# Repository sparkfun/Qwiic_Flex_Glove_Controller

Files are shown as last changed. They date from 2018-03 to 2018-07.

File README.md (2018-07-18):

SparkFun Qwiic Flex Glove Controller
========================================

SparkFun Qwiic Flex Glove Controller

[*SparkFun Qwiic Flex Glove Controller (Sen-14666)*](https://www.sparkfun.com/products/14666)

This board is a breakout for multiple flex sensors that keeps the solder points isolated to avoid breakage in wearable projects.

Repository Contents
-------------------

* **/Hardware** - Eagle design files (.brd, .sch)
* **/Libraries** - Libraries for use with the <PRODUCT NAME>
* **/Production** - Production panel files (.brd)

Documentation
--------------
* **[ADS1015 Library](https://github.com/sparkfun/SparkFun_ADS1015_Arduino_Library)** - C++ library for the ADS1015.
* **[Hookup Guide](https://learn.sparkfun.com/tutorials/qwiic-flex-glove-controller-hookup-guide)** - Basic hookup guide for the Qwiic Flex Glove Controller.

Product Versions
----------------
* [SEN-14666](https://www.sparkfun.com/products/14666)- The SparkFun Qwiic Flex Glove Controller allows you to incorporate flex sensors into a glove to control lighting, sound, and other effects making it perfect for wearable and e-textile applications. All communication is enacted exclusively via I2C, utilizing our handy Qwiic system. 

License Information
-------------------

This product is _**open source**_! 

Please review the LICENSE.md file for license information. 

If you have any questions or concerns on licensing, please contact techsupport@sparkfun.com.

Distributed as-is; no warranty is given.

- Your friends at SparkFun.

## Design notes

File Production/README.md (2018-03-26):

SparkFun <PRODUCT NAME> Production Files
=========================================

These are the production files SparkFun uses for printing PCBs.

License Information
-------------------
This product is open source! 

The hardware is released under [Creative Commons ShareAlike 4.0 International](https://creativecommons.org/licenses/by-sa/4.0/).

Please use, reuse, and modify these files as you see fit. Please maintain attribution to SparkFun Electronics and release anything derivative under the same license.

Distributed as-is; no warranty is given.

- Your friends at SparkFun.

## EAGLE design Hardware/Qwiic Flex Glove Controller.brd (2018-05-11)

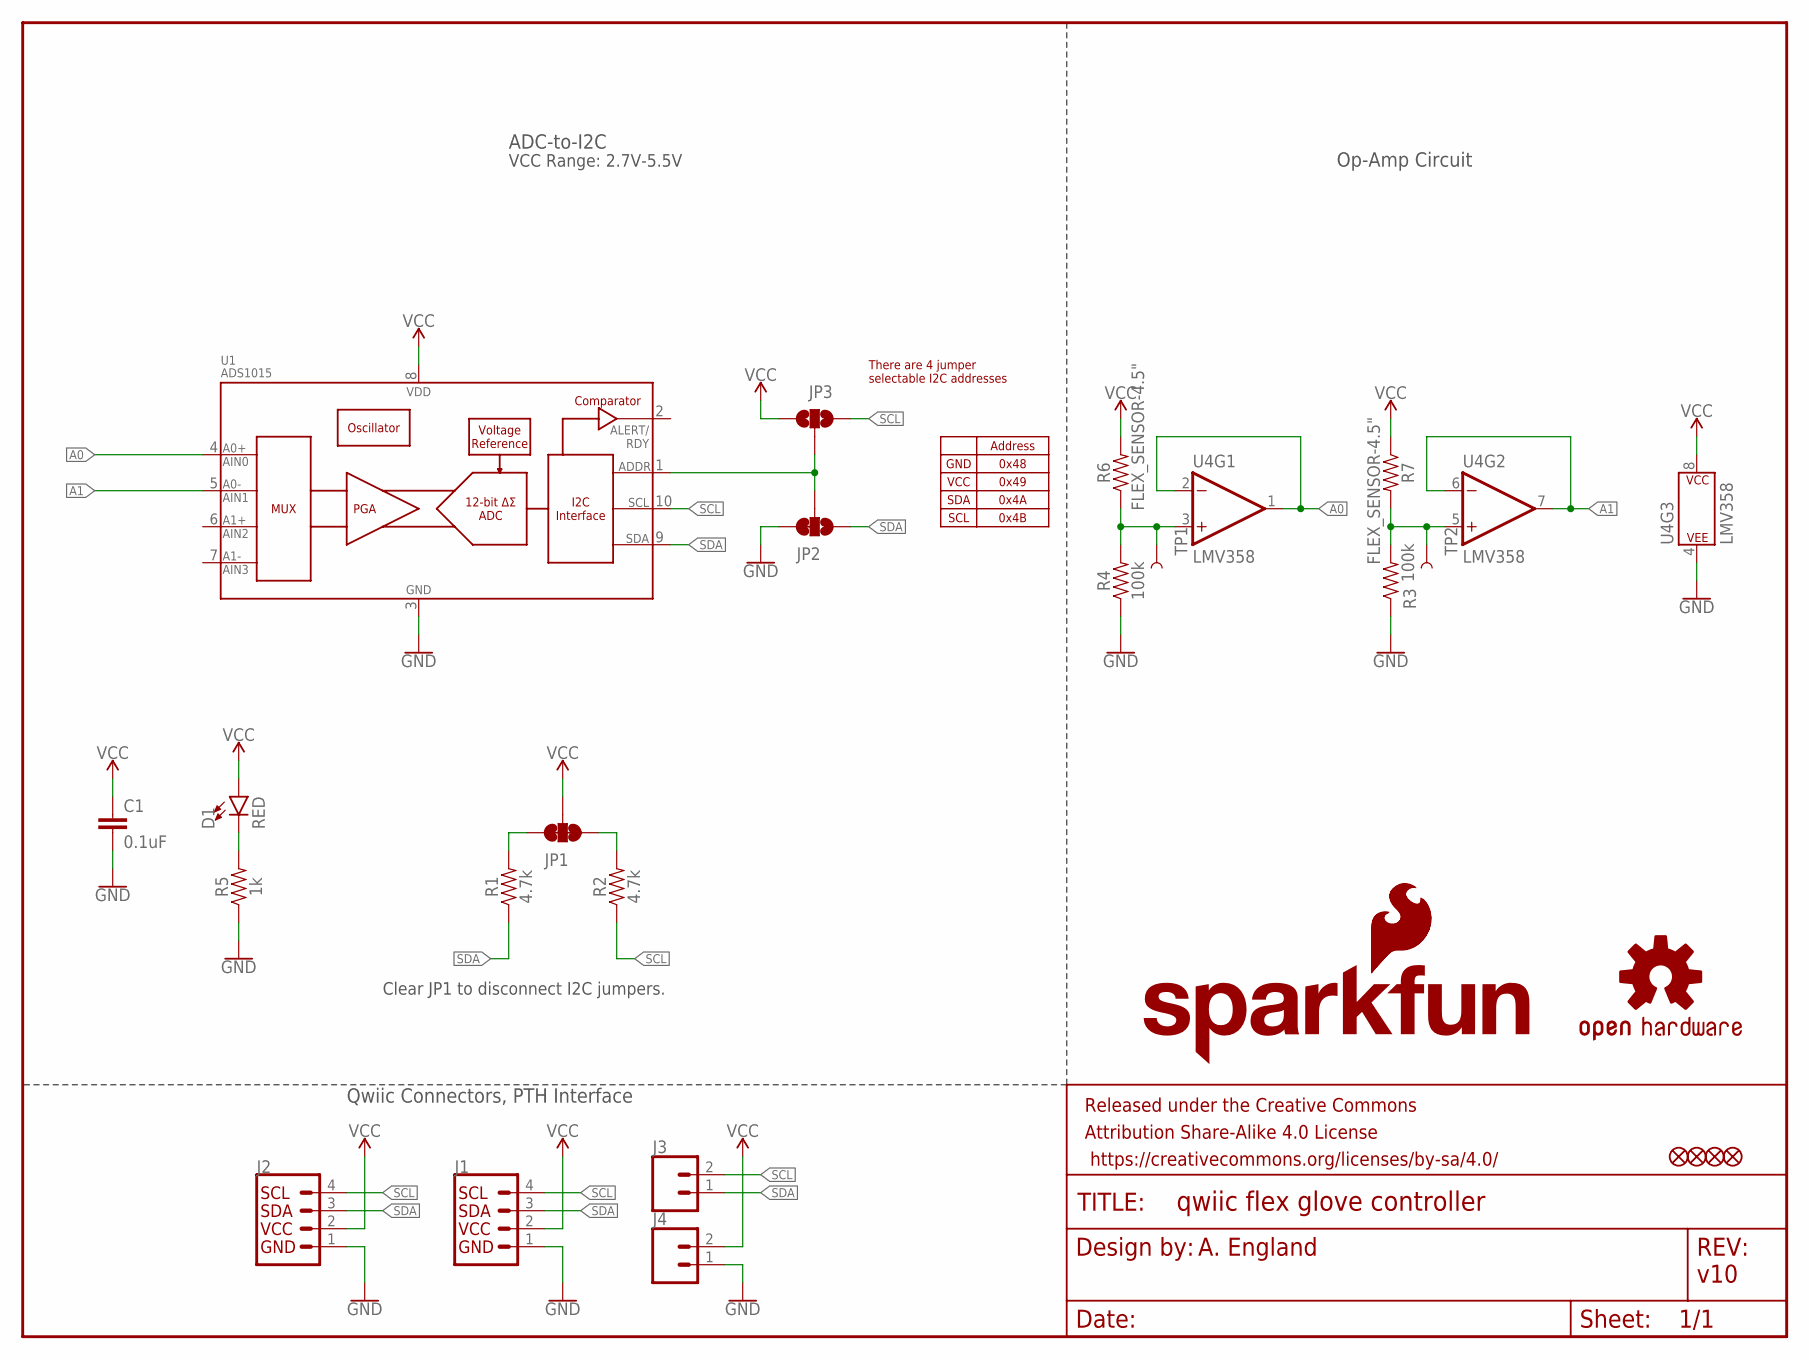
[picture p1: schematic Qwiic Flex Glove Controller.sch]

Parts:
C1: 0.1uF; 0603
D1: RED; LED-0603
FD1, FD2, FD3, FD4: FIDUCIALUFIDUCIAL; FIDUCIAL-MICRO
FRAME1: FRAME-LETTER; CREATIVE_COMMONS
J1, J2: QWIIC_CONNECTORJS-1MM; 1X04_1MM_RA
J3, J4: CONN_02; 1X02
JP1: JUMPER-SMT_3_2-NC_TRACE_NO-SILK; SMT-JUMPER_3_2-NC_TRACE_NO-SILK
JP2: JUMPER-SMT_3_1-NC_TRACE_NO-SILK; SMT-JUMPER_3_1-NC_TRACE_NO-SILK
JP3: JUMPER-SMT_3_NO_NO_SILK; SMT-JUMPER_3_0-NO_TRACE_NO-SILK
LOGO1: SFE_LOGO_NAME_FLAME.1_INCH; SFE_LOGO_NAME_FLAME_.1
LOGO2: OSHW-LOGOS; OSHW-LOGO-S
LOGO3: SFE_LOGO_FLAME.1_INCH; SFE_LOGO_FLAME_.1
R1, R2: 4.7k; 0603
R3, R4: 100k; 0603
R5: 1k; 0603
R6, R7: FLEX_SENSOR-4.5"; FLEX_SENSOR
TP1, TP2: TEST-POINT3; PAD.03X.03
U1: ADS1015; MSOP10
U4: LMV358; SO08

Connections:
A0: U1.4 (AIN0), U4.1 (OUT), U4.2 (-IN)
A1: U1.5 (AIN1), U4.6 (-IN), U4.7 (OUT)
GND: C1.2, J1.1, J2.1, J4.1, JP2.3, R3.1, R4.1, R5.1, U1.3 (VSS), U4.4 (P$V-)
unnamed: JP2.2, JP3.2, U1.1 (ADDR)
unnamed: D1.C, R5.2
unnamed: R3.2, R7.P$2 (2), TP2.P$1, U4.5 (+IN)
unnamed: R4.2, R6.P$1 (1), TP1.P$1, U4.3 (+IN)
unnamed: JP1.1, R2.2
unnamed: JP1.3, R1.2
SCL: J1.4, J2.4, J3.2, JP3.3, R2.1, U1.10 (SCL)
SDA: J1.3, J2.3, J3.1, JP2.1, R1.1, U1.9 (SDA)
VCC: C1.1, D1.A, J1.2, J2.2, J4.2, JP1.2, JP3.1, R6.P$2 (2), R7.P$1 (1), U1.8 (VDD), U4.8 (P$V+)

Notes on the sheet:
v10
Qwiic Connectors, PTH Interface
ADC-to-I2C
Op-Amp Circuit
A. England
There are 4 jumper selectable I2C addresses
Address
0x48
0x49
0x4A
0x4B
GND
VCC
SDA
SCL
VCC Range: 2.7V-5.5V
Clear JP1 to disconnect I2C jumpers.

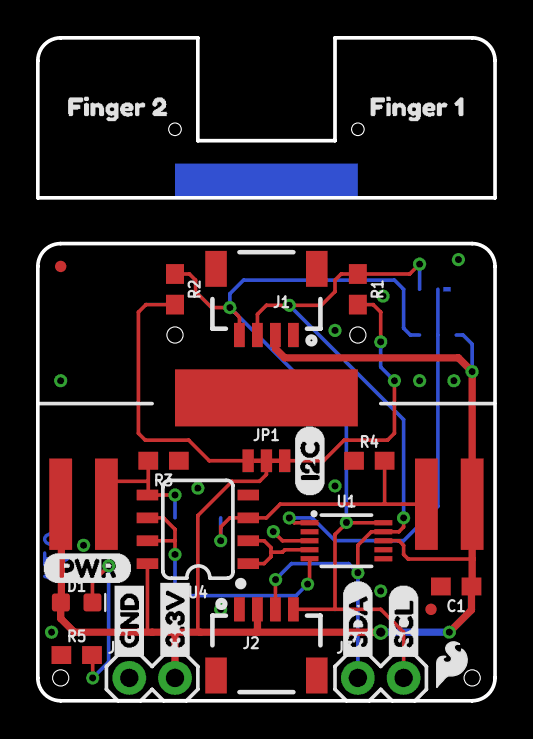
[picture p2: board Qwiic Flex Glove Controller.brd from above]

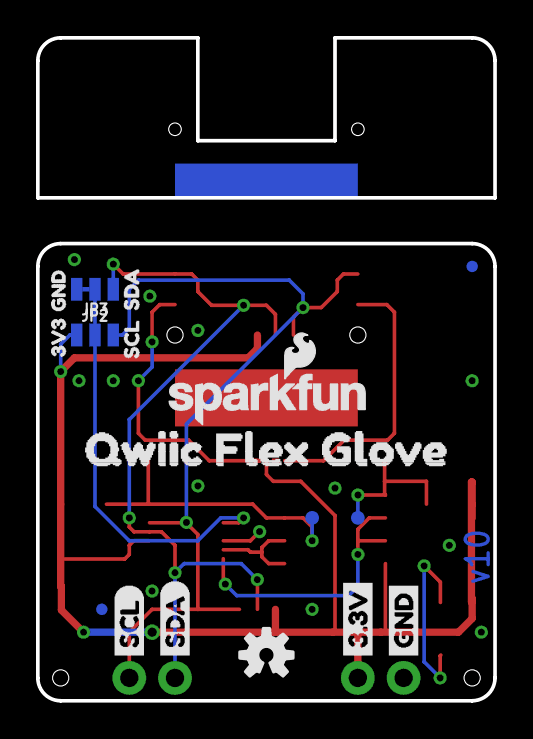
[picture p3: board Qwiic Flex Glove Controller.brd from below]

Board: 2 copper layers, 25.4 x 36.8 mm, 45 parts (17 on the bottom side), 12 nets.

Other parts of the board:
U$1, U$2: GND
U$3: 3V3-TEXT
U$4: GND-TEXT-03
U$5, U$6: 3.3V
U$7, U$8: SDA
U$9, U$10: SCL
U$11: (PWR)
U$12: SDA0
U$13: SCL2
U$14: QWIIC_FLEX_GLOVE0
U$15: I2C-()
U$16: FINGER_10
U$17: FINGER_21

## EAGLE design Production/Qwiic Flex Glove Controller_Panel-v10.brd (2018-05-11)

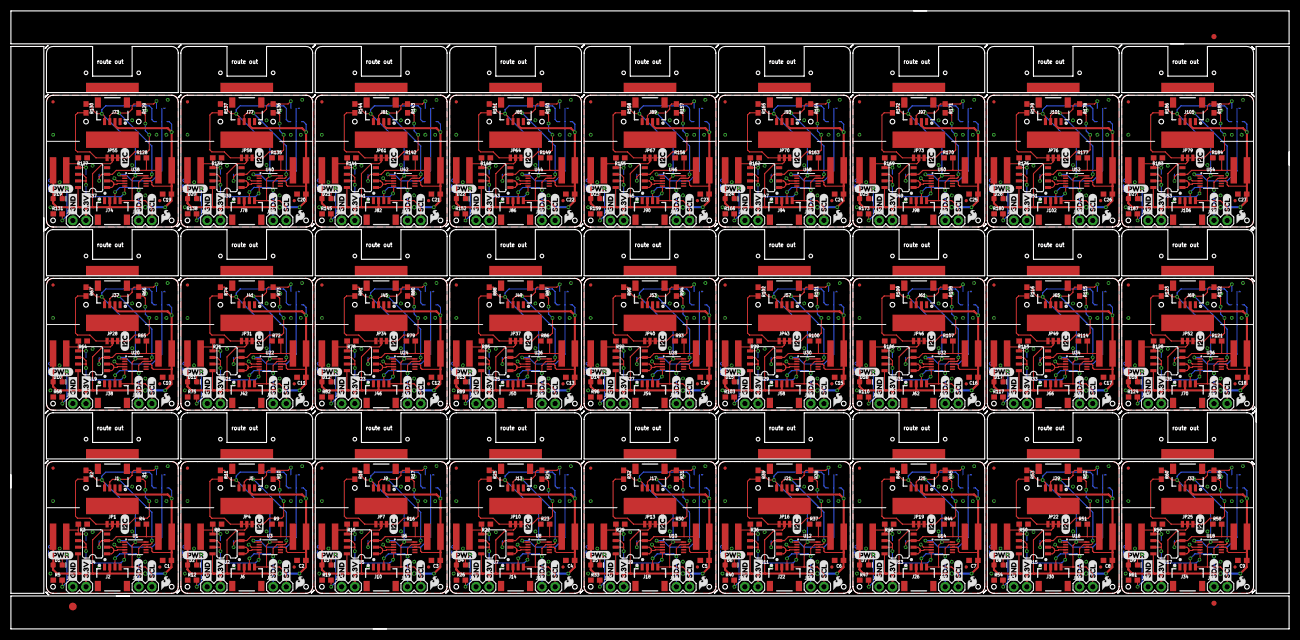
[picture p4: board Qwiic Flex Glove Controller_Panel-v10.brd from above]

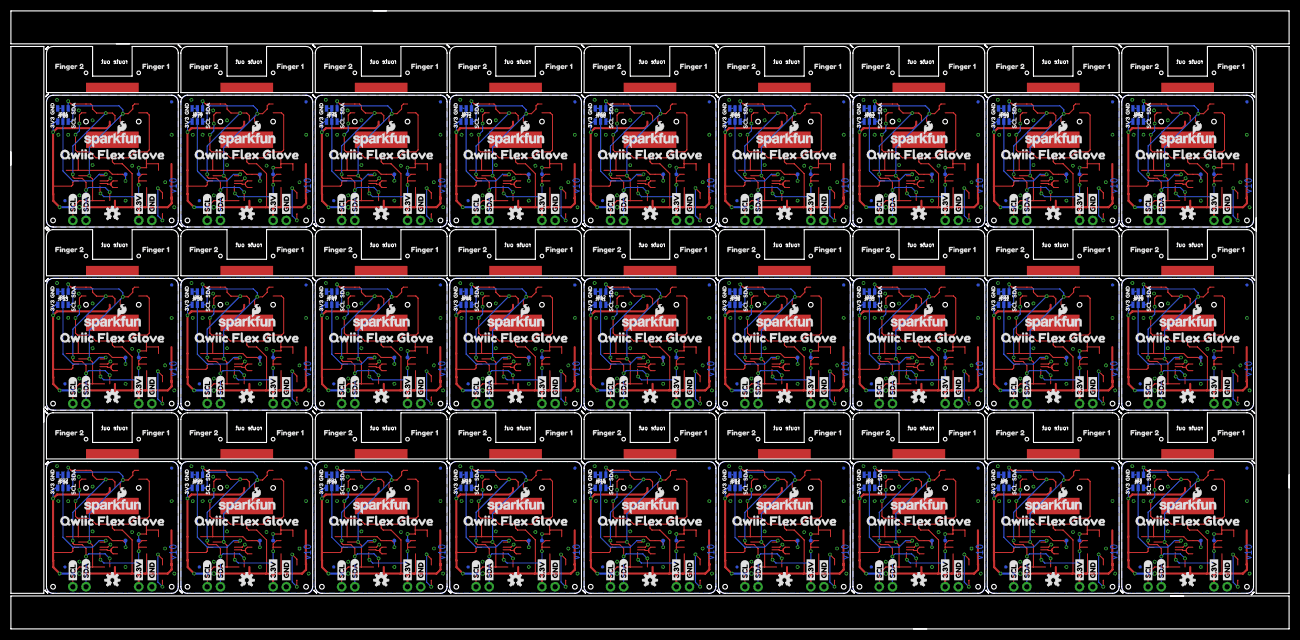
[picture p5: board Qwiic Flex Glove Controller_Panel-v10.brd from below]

Board: 2 copper layers, 246.4 x 119.1 mm, 1191 parts (513 on the bottom side), 324 nets.

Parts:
C1, C2, C3, C4, C5, C6, C7, C8, C9, C10, C11, C12, C13, C14, C15, C16, C17, C18, C19, C20, C21, C22, C23, C24, C25, C26, C27: 0.1uF; 0603
D1, D2, D3, D4, D5, D6, D7, D8, D9, D10, D11, D12, D13, D14, D15, D16, D17, D18, D19, D20, D21, D22, D23, D24, D25, D26, D27: RED; LED-0603
E$1: FIDUCIAL-1.5X3
E$5, E$6: FIDUCIAL-1X2
FD1, FD2, FD3, FD4, FD5, FD6, FD7, FD8, FD9, FD10, FD11, FD12, FD13, FD14, FD15, FD16, FD17, FD18, FD19, FD20, FD21, FD22, FD23, FD24, FD25, FD26, FD27, FD28, FD29, FD30, FD31, FD32, FD33, FD34, FD35, FD36, FD37, FD38, FD39, FD40, FD41, FD42, FD43, FD44, FD45, FD46, FD47, FD48, FD49, FD50, FD51, FD52, FD53, FD54, FD55, FD56, FD57, FD58, FD59, FD60, FD61, FD62, FD63, FD64, FD65, FD66, FD67, FD68, FD69, FD70, FD71, FD72, FD73, FD74, FD75, FD76, FD77, FD78, FD79, FD80, FD81, FD82, FD83, FD84, FD85, FD86, FD87, FD88, FD89, FD90, FD91, FD92, FD93, FD94, FD95, FD96, FD97, FD98, FD99, FD100, FD101, FD102, FD103, FD104, FD105, FD106, FD107, FD108: FIDUCIALUFIDUCIAL; FIDUCIAL-MICRO
J1, J2, J5, J6, J9, J10, J13, J14, J17, J18, J21, J22, J25, J26, J29, J30, J33, J34, J37, J38, J41, J42, J45, J46, J49, J50, J53, J54, J57, J58, J61, J62, J65, J66, J69, J70, J73, J74, J77, J78, J81, J82, J85, J86, J89, J90, J93, J94, J97, J98, J101, J102, J105, J106: 1X04_1MM_RA
J3, J4, J7, J8, J11, J12, J15, J16, J19, J20, J23, J24, J27, J28, J31, J32, J35, J36, J39, J40, J43, J44, J47, J48, J51, J52, J55, J56, J59, J60, J63, J64, J67, J68, J71, J72, J75, J76, J79, J80, J83, J84, J87, J88, J91, J92, J95, J96, J99, J100, J103, J104, J107, J108: 1X02
JP1, JP4, JP7, JP10, JP13, JP16, JP19, JP22, JP25, JP28, JP31, JP34, JP37, JP40, JP43, JP46, JP49, JP52, JP55, JP58, JP61, JP64, JP67, JP70, JP73, JP76, JP79: JUMPER-SMT_3_2-NC_TRACE_NO-SILK; SMT-JUMPER_3_2-NC_TRACE_NO-SILK
JP2, JP5, JP8, JP11, JP14, JP17, JP20, JP23, JP26, JP29, JP32, JP35, JP38, JP41, JP44, JP47, JP50, JP53, JP56, JP59, JP62, JP65, JP68, JP71, JP74, JP77, JP80: JUMPER-SMT_3_1-NC_TRACE_NO-SILK; SMT-JUMPER_3_1-NC_TRACE_NO-SILK
JP3, JP6, JP9, JP12, JP15, JP18, JP21, JP24, JP27, JP30, JP33, JP36, JP39, JP42, JP45, JP48, JP51, JP54, JP57, JP60, JP63, JP66, JP69, JP72, JP75, JP78, JP81: JUMPER-SMT_3_NO_NO_SILK; SMT-JUMPER_3_0-NO_TRACE_NO-SILK
LOGO1, LOGO4, LOGO7, LOGO10, LOGO13, LOGO16, LOGO19, LOGO22, LOGO25, LOGO28, LOGO31, LOGO34, LOGO37, LOGO40, LOGO43, LOGO46, LOGO49, LOGO52, LOGO55, LOGO58, LOGO61, LOGO64, LOGO67, LOGO70, LOGO73, LOGO76, LOGO79: SFE_LOGO_NAME_FLAME.1_INCH; SFE_LOGO_NAME_FLAME_.1
LOGO2, LOGO5, LOGO8, LOGO11, LOGO14, LOGO17, LOGO20, LOGO23, LOGO26, LOGO29, LOGO32, LOGO35, LOGO38, LOGO41, LOGO44, LOGO47, LOGO50, LOGO53, LOGO56, LOGO59, LOGO62, LOGO65, LOGO68, LOGO71, LOGO74, LOGO77, LOGO80: OSHW-LOGOS; OSHW-LOGO-S
LOGO3, LOGO6, LOGO9, LOGO12, LOGO15, LOGO18, LOGO21, LOGO24, LOGO27, LOGO30, LOGO33, LOGO36, LOGO39, LOGO42, LOGO45, LOGO48, LOGO51, LOGO54, LOGO57, LOGO60, LOGO63, LOGO66, LOGO69, LOGO72, LOGO75, LOGO78, LOGO81: SFE_LOGO_FLAME.1_INCH; SFE_LOGO_FLAME_.1
R1, R2, R10, R11, R17, R18, R24, R25, R31, R32, R38, R39, R45, R46, R52, R53, R59, R60, R66, R67, R73, R74, R80, R81, R87, R88, R94, R95, R101, R102, R108, R109, R115, R116, R122, R123, R129, R130, R136, R137, R143, R144, R150, R151, R157, R158, R164, R165, R171, R172, R178, R179, R185, R186: 4.7k; 0603
R3, R4, R8, R9, R15, R16, R22, R23, R29, R30, R36, R37, R43, R44, R50, R51, R57, R58, R64, R65, R71, R72, R78, R79, R85, R86, R92, R93, R99, R100, R106, R107, R113, R114, R120, R121, R127, R128, R134, R135, R141, R142, R148, R149, R155, R156, R162, R163, R169, R170, R176, R177, R183, R184: 100k; 0603
R5, R12, R19, R26, R33, R40, R47, R54, R61, R68, R75, R82, R89, R96, R103, R110, R117, R124, R131, R138, R145, R152, R159, R166, R173, R180, R187: 1k; 0603
R6, R7, R13, R14, R20, R21, R27, R28, R34, R35, R41, R42, R48, R49, R55, R56, R62, R63, R69, R70, R76, R77, R83, R84, R90, R91, R97, R98, R104, R105, R111, R112, R118, R119, R125, R126, R132, R133, R139, R140, R146, R147, R153, R154, R160, R161, R167, R168, R174, R175, R181, R182, R188, R189: FLEX_SENSOR-4.5"; FLEX_SENSOR
TP1, TP2, TP3, TP4, TP5, TP6, TP7, TP8, TP9, TP10, TP11, TP12, TP13, TP14, TP15, TP16, TP17, TP18, TP19, TP20, TP21, TP22, TP23, TP24, TP25, TP26, TP27, TP28, TP29, TP30, TP31, TP32, TP33, TP34, TP35, TP36, TP37, TP38, TP39, TP40, TP41, TP42, TP43, TP44, TP45, TP46, TP47, TP48, TP49, TP50, TP51, TP52, TP53, TP54: TEST-POINT3; PAD.03X.03
U1, U3, U6, U8, U10, U12, U14, U16, U18, U20, U22, U24, U26, U28, U30, U32, U34, U36, U38, U40, U42, U44, U46, U48, U50, U52, U54: ADS1015; MSOP10
U2, U4, U5, U7, U9, U11, U13, U15, U17, U19, U21, U23, U25, U27, U29, U31, U33, U35, U37, U39, U41, U43, U45, U47, U49, U51, U53: LMV358; SO08
U$1, U$2, U$18, U$19, U$35, U$36, U$52, U$53, U$69, U$70, U$86, U$87, U$103, U$104, U$120, U$121, U$137, U$138, U$154, U$155, U$171, U$172, U$188, U$189, U$205, U$206, U$222, U$223, U$239, U$240, U$256, U$257, U$273, U$274, U$290, U$291, U$307, U$308, U$324, U$325, U$341, U$342, U$358, U$359, U$375, U$376, U$392, U$393, U$409, U$410, U$426, U$427, U$443, U$444: GND
U$3, U$27, U$44, U$61, U$78, U$95, U$112, U$129, U$146, U$163, U$180, U$197, U$214, U$231, U$248, U$265, U$282, U$299, U$316, U$333, U$350, U$367, U$384, U$401, U$418, U$435, U$452: 3V3-TEXT
U$4, U$28, U$45, U$62, U$79, U$96, U$113, U$130, U$147, U$164, U$181, U$198, U$215, U$232, U$249, U$266, U$283, U$300, U$317, U$334, U$351, U$368, U$385, U$402, U$419, U$436, U$453: GND-TEXT-03
U$5, U$6, U$20, U$21, U$37, U$38, U$54, U$55, U$71, U$72, U$88, U$89, U$105, U$106, U$122, U$123, U$139, U$140, U$156, U$157, U$173, U$174, U$190, U$191, U$207, U$208, U$224, U$225, U$241, U$242, U$258, U$259, U$275, U$276, U$292, U$293, U$309, U$310, U$326, U$327, U$343, U$344, U$360, U$361, U$377, U$378, U$394, U$395, U$411, U$412, U$428, U$429, U$445, U$446: 3.3V
U$7, U$8, U$22, U$23, U$39, U$40, U$56, U$57, U$73, U$74, U$90, U$91, U$107, U$108, U$124, U$125, U$141, U$142, U$158, U$159, U$175, U$176, U$192, U$193, U$209, U$210, U$226, U$227, U$243, U$244, U$260, U$261, U$277, U$278, U$294, U$295, U$311, U$312, U$328, U$329, U$345, U$346, U$362, U$363, U$379, U$380, U$396, U$397, U$413, U$414, U$430, U$431, U$447, U$448: SDA
U$9, U$10, U$24, U$25, U$41, U$42, U$58, U$59, U$75, U$76, U$92, U$93, U$109, U$110, U$126, U$127, U$143, U$144, U$160, U$161, U$177, U$178, U$194, U$195, U$211, U$212, U$228, U$229, U$245, U$246, U$262, U$263, U$279, U$280, U$296, U$297, U$313, U$314, U$330, U$331, U$347, U$348, U$364, U$365, U$381, U$382, U$398, U$399, U$415, U$416, U$432, U$433, U$449, U$450: SCL
U$11, U$26, U$43, U$60, U$77, U$94, U$111, U$128, U$145, U$162, U$179, U$196, U$213, U$230, U$247, U$264, U$281, U$298, U$315, U$332, U$349, U$366, U$383, U$400, U$417, U$434, U$451: (PWR)
U$12, U$29, U$46, U$63, U$80, U$97, U$114, U$131, U$148, U$165, U$182, U$199, U$216, U$233, U$250, U$267, U$284, U$301, U$318, U$335, U$352, U$369, U$386, U$403, U$420, U$437, U$454: SDA0
U$13, U$30, U$47, U$64, U$81, U$98, U$115, U$132, U$149, U$166, U$183, U$200, U$217, U$234, U$251, U$268, U$285, U$302, U$319, U$336, U$353, U$370, U$387, U$404, U$421, U$438, U$455: SCL2
U$14, U$32, U$49, U$66, U$83, U$100, U$117, U$134, U$151, U$168, U$185, U$202, U$219, U$236, U$253, U$270, U$287, U$304, U$321, U$338, U$355, U$372, U$389, U$406, U$423, U$440, U$457: QWIIC_FLEX_GLOVE0
U$15, U$31, U$48, U$65, U$82, U$99, U$116, U$133, U$150, U$167, U$184, U$201, U$218, U$235, U$252, U$269, U$286, U$303, U$320, U$337, U$354, U$371, U$388, U$405, U$422, U$439, U$456: I2C-()
U$16, U$33, U$50, U$67, U$84, U$101, U$118, U$135, U$152, U$169, U$186, U$203, U$220, U$237, U$254, U$271, U$288, U$305, U$322, U$339, U$356, U$373, U$390, U$407, U$424, U$441, U$458: FINGER_10
U$17, U$34, U$51, U$68, U$85, U$102, U$119, U$136, U$153, U$170, U$187, U$204, U$221, U$238, U$255, U$272, U$289, U$306, U$323, U$340, U$357, U$374, U$391, U$408, U$425, U$442, U$459: FINGER_21

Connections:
A0: U1.4, U4.1, U4.2
A1: U1.5, U4.6, U4.7
A2: U2.1, U2.2, U3.4
A3: U2.6, U2.7, U3.5
A4: U5.1, U5.2, U6.4
A5: U5.6, U5.7, U6.5
A6: U7.1, U7.2, U8.4
A7: U7.6, U7.7, U8.5
A8: U9.1, U9.2, U10.4
A9: U9.6, U9.7, U10.5
A10: U11.1, U11.2, U12.4
A11: U11.6, U11.7, U12.5
A12: U13.1, U13.2, U14.4
A13: U13.6, U13.7, U14.5
A14: U15.1, U15.2, U16.4
A15: U15.6, U15.7, U16.5
A16: U17.1, U17.2, U18.4
A17: U17.6, U17.7, U18.5
A18: U19.1, U19.2, U20.4
A19: U19.6, U19.7, U20.5
A20: U21.1, U21.2, U22.4
A21: U21.6, U21.7, U22.5
A22: U23.1, U23.2, U24.4
A23: U23.6, U23.7, U24.5
A24: U25.1, U25.2, U26.4
A25: U25.6, U25.7, U26.5
A26: U27.1, U27.2, U28.4
A27: U27.6, U27.7, U28.5
A28: U29.1, U29.2, U30.4
A29: U29.6, U29.7, U30.5
A30: U31.1, U31.2, U32.4
A31: U31.6, U31.7, U32.5
A32: U33.1, U33.2, U34.4
A33: U33.6, U33.7, U34.5
A34: U35.1, U35.2, U36.4
A35: U35.6, U35.7, U36.5
A36: U37.1, U37.2, U38.4
A37: U37.6, U37.7, U38.5
A38: U39.1, U39.2, U40.4
A39: U39.6, U39.7, U40.5
A40: U41.1, U41.2, U42.4
A41: U41.6, U41.7, U42.5
A42: U43.1, U43.2, U44.4
A43: U43.6, U43.7, U44.5
A44: U45.1, U45.2, U46.4
A45: U45.6, U45.7, U46.5
A46: U47.1, U47.2, U48.4
A47: U47.6, U47.7, U48.5
A48: U49.1, U49.2, U50.4
A49: U49.6, U49.7, U50.5
A50: U51.1, U51.2, U52.4
A51: U51.6, U51.7, U52.5
A52: U53.1, U53.2, U54.4
A53: U53.6, U53.7, U54.5
GND: C1.2, J1.1, J2.1, J4.1, JP2.3, R3.1, R4.1, R5.1, U1.3, U4.4
GND1: C2.2, J5.1, J6.1, J8.1, JP5.3, R8.1, R9.1, R12.1, U2.4, U3.3
GND2: C3.2, J9.1, J10.1, J12.1, JP8.3, R15.1, R16.1, R19.1, U5.4, U6.3
GND3: C4.2, J13.1, J14.1, J16.1, JP11.3, R22.1, R23.1, R26.1, U7.4, U8.3
GND4: C5.2, J17.1, J18.1, J20.1, JP14.3, R29.1, R30.1, R33.1, U9.4, U10.3
GND5: C6.2, J21.1, J22.1, J24.1, JP17.3, R36.1, R37.1, R40.1, U11.4, U12.3
GND6: C7.2, J25.1, J26.1, J28.1, JP20.3, R43.1, R44.1, R47.1, U13.4, U14.3
GND7: C8.2, J29.1, J30.1, J32.1, JP23.3, R50.1, R51.1, R54.1, U15.4, U16.3
GND8: C9.2, J33.1, J34.1, J36.1, JP26.3, R57.1, R58.1, R61.1, U17.4, U18.3
GND9: C10.2, J37.1, J38.1, J40.1, JP29.3, R64.1, R65.1, R68.1, U19.4, U20.3
GND10: C11.2, J41.1, J42.1, J44.1, JP32.3, R71.1, R72.1, R75.1, U21.4, U22.3
GND11: C12.2, J45.1, J46.1, J48.1, JP35.3, R78.1, R79.1, R82.1, U23.4, U24.3
GND12: C13.2, J49.1, J50.1, J52.1, JP38.3, R85.1, R86.1, R89.1, U25.4, U26.3
GND13: C14.2, J53.1, J54.1, J56.1, JP41.3, R92.1, R93.1, R96.1, U27.4, U28.3
GND14: C15.2, J57.1, J58.1, J60.1, JP44.3, R99.1, R100.1, R103.1, U29.4, U30.3
GND15: C16.2, J61.1, J62.1, J64.1, JP47.3, R106.1, R107.1, R110.1, U31.4, U32.3
GND16: C17.2, J65.1, J66.1, J68.1, JP50.3, R113.1, R114.1, R117.1, U33.4, U34.3
GND17: C18.2, J69.1, J70.1, J72.1, JP53.3, R120.1, R121.1, R124.1, U35.4, U36.3
GND18: C19.2, J73.1, J74.1, J76.1, JP56.3, R127.1, R128.1, R131.1, U37.4, U38.3
GND19: C20.2, J77.1, J78.1, J80.1, JP59.3, R134.1, R135.1, R138.1, U39.4, U40.3
GND20: C21.2, J81.1, J82.1, J84.1, JP62.3, R141.1, R142.1, R145.1, U41.4, U42.3
GND21: C22.2, J85.1, J86.1, J88.1, JP65.3, R148.1, R149.1, R152.1, U43.4, U44.3
GND22: C23.2, J89.1, J90.1, J92.1, JP68.3, R155.1, R156.1, R159.1, U45.4, U46.3
GND23: C24.2, J93.1, J94.1, J96.1, JP71.3, R162.1, R163.1, R166.1, U47.4, U48.3
GND24: C25.2, J97.1, J98.1, J100.1, JP74.3, R169.1, R170.1, R173.1, U49.4, U50.3
GND25: C26.2, J101.1, J102.1, J104.1, JP77.3, R176.1, R177.1, R180.1, U51.4, U52.3
GND26: C27.2, J105.1, J106.1, J108.1, JP80.3, R183.1, R184.1, R187.1, U53.4, U54.3
unnamed: JP2.2, JP3.2, U1.1
unnamed: D1.C, R5.2
unnamed: R3.2, R7.P$2, TP2.P$1, U4.5
unnamed: R4.2, R6.P$1, TP1.P$1, U4.3
unnamed: R8.2, R14.P$2, TP4.P$1, U2.5
unnamed: R9.2, R13.P$1, TP3.P$1, U2.3
unnamed: JP1.1, R2.2
unnamed: JP1.3, R1.2
unnamed: JP4.1, R11.2
unnamed: JP4.3, R10.2
unnamed: JP5.2, JP6.2, U3.1
unnamed: D2.C, R12.2
unnamed: R15.2, R21.P$2, TP6.P$1, U5.5
unnamed: R16.2, R20.P$1, TP5.P$1, U5.3
unnamed: JP7.1, R18.2
unnamed: JP7.3, R17.2
unnamed: JP8.2, JP9.2, U6.1
unnamed: D3.C, R19.2
unnamed: R22.2, R28.P$2, TP8.P$1, U7.5
unnamed: R23.2, R27.P$1, TP7.P$1, U7.3
unnamed: JP10.1, R25.2
unnamed: JP10.3, R24.2
unnamed: JP11.2, JP12.2, U8.1
unnamed: D4.C, R26.2
unnamed: R29.2, R35.P$2, TP10.P$1, U9.5
unnamed: R30.2, R34.P$1, TP9.P$1, U9.3
unnamed: JP13.1, R32.2
unnamed: JP13.3, R31.2
unnamed: JP14.2, JP15.2, U10.1
unnamed: D5.C, R33.2
unnamed: R36.2, R42.P$2, TP12.P$1, U11.5
unnamed: R37.2, R41.P$1, TP11.P$1, U11.3
unnamed: JP16.1, R39.2
unnamed: JP16.3, R38.2
unnamed: JP17.2, JP18.2, U12.1
unnamed: D6.C, R40.2
unnamed: R43.2, R49.P$2, TP14.P$1, U13.5
unnamed: R44.2, R48.P$1, TP13.P$1, U13.3
unnamed: JP19.1, R46.2
unnamed: JP19.3, R45.2
unnamed: JP20.2, JP21.2, U14.1
unnamed: D7.C, R47.2
unnamed: R50.2, R56.P$2, TP16.P$1, U15.5
unnamed: R51.2, R55.P$1, TP15.P$1, U15.3
unnamed: JP22.1, R53.2
unnamed: JP22.3, R52.2
unnamed: JP23.2, JP24.2, U16.1
unnamed: D8.C, R54.2
unnamed: R57.2, R63.P$2, TP18.P$1, U17.5
unnamed: R58.2, R62.P$1, TP17.P$1, U17.3
unnamed: JP25.1, R60.2
unnamed: JP25.3, R59.2
unnamed: JP26.2, JP27.2, U18.1
unnamed: D9.C, R61.2
unnamed: R64.2, R70.P$2, TP20.P$1, U19.5
unnamed: R65.2, R69.P$1, TP19.P$1, U19.3
unnamed: JP28.1, R67.2
unnamed: JP28.3, R66.2
unnamed: JP29.2, JP30.2, U20.1
unnamed: D10.C, R68.2
unnamed: R71.2, R77.P$2, TP22.P$1, U21.5
unnamed: R72.2, R76.P$1, TP21.P$1, U21.3
unnamed: JP31.1, R74.2
unnamed: JP31.3, R73.2
unnamed: JP32.2, JP33.2, U22.1
unnamed: D11.C, R75.2
unnamed: R78.2, R84.P$2, TP24.P$1, U23.5
unnamed: R79.2, R83.P$1, TP23.P$1, U23.3
unnamed: JP34.1, R81.2
unnamed: JP34.3, R80.2
unnamed: JP35.2, JP36.2, U24.1
unnamed: D12.C, R82.2
unnamed: R85.2, R91.P$2, TP26.P$1, U25.5
unnamed: R86.2, R90.P$1, TP25.P$1, U25.3
unnamed: JP37.1, R88.2
unnamed: JP37.3, R87.2
unnamed: JP38.2, JP39.2, U26.1
unnamed: D13.C, R89.2
unnamed: R92.2, R98.P$2, TP28.P$1, U27.5
unnamed: R93.2, R97.P$1, TP27.P$1, U27.3
unnamed: JP40.1, R95.2
unnamed: JP40.3, R94.2
unnamed: JP41.2, JP42.2, U28.1
unnamed: D14.C, R96.2
unnamed: R99.2, R105.P$2, TP30.P$1, U29.5
unnamed: R100.2, R104.P$1, TP29.P$1, U29.3
unnamed: JP43.1, R102.2
unnamed: JP43.3, R101.2
unnamed: JP44.2, JP45.2, U30.1
unnamed: D15.C, R103.2
unnamed: R106.2, R112.P$2, TP32.P$1, U31.5
unnamed: R107.2, R111.P$1, TP31.P$1, U31.3
unnamed: JP46.1, R109.2
unnamed: JP46.3, R108.2
unnamed: JP47.2, JP48.2, U32.1
unnamed: D16.C, R110.2
unnamed: R113.2, R119.P$2, TP34.P$1, U33.5
unnamed: R114.2, R118.P$1, TP33.P$1, U33.3
unnamed: JP49.1, R116.2
unnamed: JP49.3, R115.2
unnamed: JP50.2, JP51.2, U34.1
unnamed: D17.C, R117.2
unnamed: R120.2, R126.P$2, TP36.P$1, U35.5
unnamed: R121.2, R125.P$1, TP35.P$1, U35.3
unnamed: JP52.1, R123.2
unnamed: JP52.3, R122.2
unnamed: JP53.2, JP54.2, U36.1
unnamed: D18.C, R124.2
unnamed: R127.2, R133.P$2, TP38.P$1, U37.5
unnamed: R128.2, R132.P$1, TP37.P$1, U37.3
unnamed: JP55.1, R130.2
unnamed: JP55.3, R129.2
unnamed: JP56.2, JP57.2, U38.1
unnamed: D19.C, R131.2
unnamed: R134.2, R140.P$2, TP40.P$1, U39.5
unnamed: R135.2, R139.P$1, TP39.P$1, U39.3
unnamed: JP58.1, R137.2
unnamed: JP58.3, R136.2
unnamed: JP59.2, JP60.2, U40.1
unnamed: D20.C, R138.2
unnamed: R141.2, R147.P$2, TP42.P$1, U41.5
unnamed: R142.2, R146.P$1, TP41.P$1, U41.3
unnamed: JP61.1, R144.2
unnamed: JP61.3, R143.2
unnamed: JP62.2, JP63.2, U42.1
unnamed: D21.C, R145.2
unnamed: R148.2, R154.P$2, TP44.P$1, U43.5
unnamed: R149.2, R153.P$1, TP43.P$1, U43.3
unnamed: JP64.1, R151.2
unnamed: JP64.3, R150.2
unnamed: JP65.2, JP66.2, U44.1
unnamed: D22.C, R152.2
unnamed: R155.2, R161.P$2, TP46.P$1, U45.5
unnamed: R156.2, R160.P$1, TP45.P$1, U45.3
unnamed: JP67.1, R158.2
unnamed: JP67.3, R157.2
unnamed: JP68.2, JP69.2, U46.1
unnamed: D23.C, R159.2
unnamed: R162.2, R168.P$2, TP48.P$1, U47.5
unnamed: R163.2, R167.P$1, TP47.P$1, U47.3
unnamed: JP70.1, R165.2
unnamed: JP70.3, R164.2
unnamed: JP71.2, JP72.2, U48.1
unnamed: D24.C, R166.2
unnamed: R169.2, R175.P$2, TP50.P$1, U49.5
unnamed: R170.2, R174.P$1, TP49.P$1, U49.3
unnamed: JP73.1, R172.2
unnamed: JP73.3, R171.2
unnamed: JP74.2, JP75.2, U50.1
unnamed: D25.C, R173.2
unnamed: R176.2, R182.P$2, TP52.P$1, U51.5
unnamed: R177.2, R181.P$1, TP51.P$1, U51.3
unnamed: JP76.1, R179.2
unnamed: JP76.3, R178.2
unnamed: JP77.2, JP78.2, U52.1
unnamed: D26.C, R180.2
unnamed: R183.2, R189.P$2, TP54.P$1, U53.5
unnamed: R184.2, R188.P$1, TP53.P$1, U53.3
unnamed: JP79.1, R186.2
unnamed: JP79.3, R185.2
unnamed: JP80.2, JP81.2, U54.1
unnamed: D27.C, R187.2
SCL: J1.4, J2.4, J3.2, JP3.3, R2.1, U1.10
SCL1: J5.4, J6.4, J7.2, JP6.3, R11.1, U3.10
SCL2: J9.4, J10.4, J11.2, JP9.3, R18.1, U6.10
SCL3: J13.4, J14.4, J15.2, JP12.3, R25.1, U8.10
SCL4: J17.4, J18.4, J19.2, JP15.3, R32.1, U10.10
SCL5: J21.4, J22.4, J23.2, JP18.3, R39.1, U12.10
SCL6: J25.4, J26.4, J27.2, JP21.3, R46.1, U14.10
SCL7: J29.4, J30.4, J31.2, JP24.3, R53.1, U16.10
SCL8: J33.4, J34.4, J35.2, JP27.3, R60.1, U18.10
SCL9: J37.4, J38.4, J39.2, JP30.3, R67.1, U20.10
SCL10: J41.4, J42.4, J43.2, JP33.3, R74.1, U22.10
SCL11: J45.4, J46.4, J47.2, JP36.3, R81.1, U24.10
SCL12: J49.4, J50.4, J51.2, JP39.3, R88.1, U26.10
SCL13: J53.4, J54.4, J55.2, JP42.3, R95.1, U28.10
SCL14: J57.4, J58.4, J59.2, JP45.3, R102.1, U30.10
SCL15: J61.4, J62.4, J63.2, JP48.3, R109.1, U32.10
SCL16: J65.4, J66.4, J67.2, JP51.3, R116.1, U34.10
SCL17: J69.4, J70.4, J71.2, JP54.3, R123.1, U36.10
SCL18: J73.4, J74.4, J75.2, JP57.3, R130.1, U38.10
SCL19: J77.4, J78.4, J79.2, JP60.3, R137.1, U40.10
SCL20: J81.4, J82.4, J83.2, JP63.3, R144.1, U42.10
SCL21: J85.4, J86.4, J87.2, JP66.3, R151.1, U44.10
SCL22: J89.4, J90.4, J91.2, JP69.3, R158.1, U46.10
SCL23: J93.4, J94.4, J95.2, JP72.3, R165.1, U48.10
SCL24: J97.4, J98.4, J99.2, JP75.3, R172.1, U50.10
SCL25: J101.4, J102.4, J103.2, JP78.3, R179.1, U52.10
SCL26: J105.4, J106.4, J107.2, JP81.3, R186.1, U54.10
SDA: J1.3, J2.3, J3.1, JP2.1, R1.1, U1.9
SDA1: J5.3, J6.3, J7.1, JP5.1, R10.1, U3.9
SDA2: J9.3, J10.3, J11.1, JP8.1, R17.1, U6.9
SDA3: J13.3, J14.3, J15.1, JP11.1, R24.1, U8.9
SDA4: J17.3, J18.3, J19.1, JP14.1, R31.1, U10.9
SDA5: J21.3, J22.3, J23.1, JP17.1, R38.1, U12.9
SDA6: J25.3, J26.3, J27.1, JP20.1, R45.1, U14.9
SDA7: J29.3, J30.3, J31.1, JP23.1, R52.1, U16.9
SDA8: J33.3, J34.3, J35.1, JP26.1, R59.1, U18.9
SDA9: J37.3, J38.3, J39.1, JP29.1, R66.1, U20.9
SDA10: J41.3, J42.3, J43.1, JP32.1, R73.1, U22.9
SDA11: J45.3, J46.3, J47.1, JP35.1, R80.1, U24.9
SDA12: J49.3, J50.3, J51.1, JP38.1, R87.1, U26.9
SDA13: J53.3, J54.3, J55.1, JP41.1, R94.1, U28.9
SDA14: J57.3, J58.3, J59.1, JP44.1, R101.1, U30.9
SDA15: J61.3, J62.3, J63.1, JP47.1, R108.1, U32.9
SDA16: J65.3, J66.3, J67.1, JP50.1, R115.1, U34.9
SDA17: J69.3, J70.3, J71.1, JP53.1, R122.1, U36.9
SDA18: J73.3, J74.3, J75.1, JP56.1, R129.1, U38.9
SDA19: J77.3, J78.3, J79.1, JP59.1, R136.1, U40.9
SDA20: J81.3, J82.3, J83.1, JP62.1, R143.1, U42.9
SDA21: J85.3, J86.3, J87.1, JP65.1, R150.1, U44.9
SDA22: J89.3, J90.3, J91.1, JP68.1, R157.1, U46.9
SDA23: J93.3, J94.3, J95.1, JP71.1, R164.1, U48.9
SDA24: J97.3, J98.3, J99.1, JP74.1, R171.1, U50.9
SDA25: J101.3, J102.3, J103.1, JP77.1, R178.1, U52.9
SDA26: J105.3, J106.3, J107.1, JP80.1, R185.1, U54.9
VCC: C1.1, D1.A, J1.2, J2.2, J4.2, JP1.2, JP3.1, R6.P$2, R7.P$1, U1.8, U4.8
VCC1: C2.1, D2.A, J5.2, J6.2, J8.2, JP4.2, JP6.1, R13.P$2, R14.P$1, U2.8, U3.8
VCC2: C3.1, D3.A, J9.2, J10.2, J12.2, JP7.2, JP9.1, R20.P$2, R21.P$1, U5.8, U6.8
VCC3: C4.1, D4.A, J13.2, J14.2, J16.2, JP10.2, JP12.1, R27.P$2, R28.P$1, U7.8, U8.8
VCC4: C5.1, D5.A, J17.2, J18.2, J20.2, JP13.2, JP15.1, R34.P$2, R35.P$1, U9.8, U10.8
VCC5: C6.1, D6.A, J21.2, J22.2, J24.2, JP16.2, JP18.1, R41.P$2, R42.P$1, U11.8, U12.8
VCC6: C7.1, D7.A, J25.2, J26.2, J28.2, JP19.2, JP21.1, R48.P$2, R49.P$1, U13.8, U14.8
VCC7: C8.1, D8.A, J29.2, J30.2, J32.2, JP22.2, JP24.1, R55.P$2, R56.P$1, U15.8, U16.8
VCC8: C9.1, D9.A, J33.2, J34.2, J36.2, JP25.2, JP27.1, R62.P$2, R63.P$1, U17.8, U18.8
VCC9: C10.1, D10.A, J37.2, J38.2, J40.2, JP28.2, JP30.1, R69.P$2, R70.P$1, U19.8, U20.8
VCC10: C11.1, D11.A, J41.2, J42.2, J44.2, JP31.2, JP33.1, R76.P$2, R77.P$1, U21.8, U22.8
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

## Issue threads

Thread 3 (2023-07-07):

Qwiic_Flex_Glove_Controller Questuion

jendy12345, 2023-07-07:
Hello,I have some questions:
1. Are the addresses of these I2C addresses fixed? What if I want to set a different address?
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
2. Suppose I want to use three different addresses at the same time, is this possible?

jendy12345, 2023-07-31:
Hello, is there any problem with ADS1015 qwiic flex sensor connecting to bluno beetle bluetooth? Because the scl and sda of this sensor seem to interfere with each other. When I only plug in one of scl and sda, the bluetooth light will be on, but when I plug in both scl and sda, the bluetooth light will not be on. Excuse me why is that? Is there any solution?

This is how I wire it up：
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

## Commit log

2018-03-26 removed original files
    [gloves.brd, gloves.sch]
2018-03-26 updated board to sfe standards
    [Qwiic Glove.brd, Qwiic Glove.sch]
2018-03-26 PWR label
    [Qwiic Glove.brd]
2018-03-30 post checklist changes
    [Qwiic Glove.brd, Qwiic Glove.sch]
2018-03-30 fixed text issue
    [Qwiic Glove.sch]
2018-05-07 post review changes
    [Board_Design_Checklist.xls, Qwiic Glove.brd, Qwiic Glove.sch]
2018-05-08 updated silk for name, post QC changes
    [Qwiic Flex Glove Controller.brd, Qwiic Flex Glove Controller.sch]
2018-05-08 cleaned repo
    [Qwiic Flex Glove Controller.brd, Qwiic Glove.brd, Qwiic Glove.sch]
2018-05-08 added buzzard finger labels
    [Qwiic Flex Glove Controller.brd]
2018-05-09 changed to Trace Jumper
    [Qwiic Flex Glove Controller.brd, Qwiic Flex Glove Controller.sch]
2018-05-09 created panel v10
    [Qwiic Flex Glove Controller_Panel-v10.brd]
2018-05-11 Added panel
    [Qwiic Flex Glove Controller.GBL, Qwiic Flex Glove Controller.GBO, Qwiic Flex Glove Controller.GBS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]
2018-07-17 updating repo for release
    [Board_Design_Checklist.xls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]
2018-07-17 Squashed 'Libraries/Arduino/' content from commit df423cb
    git-subtree-dir: Libraries/Arduino
    git-subtree-split: df423cb850072d5ad2a2f6ba829ed9c92971c209

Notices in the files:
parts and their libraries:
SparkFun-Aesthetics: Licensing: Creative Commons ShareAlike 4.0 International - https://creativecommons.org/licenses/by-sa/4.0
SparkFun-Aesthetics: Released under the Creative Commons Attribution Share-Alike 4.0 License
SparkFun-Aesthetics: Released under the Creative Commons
